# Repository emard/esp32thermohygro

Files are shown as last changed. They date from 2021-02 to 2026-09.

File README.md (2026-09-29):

# THERMOHYGROMETER

ESP32 2-channel SHT75/SHT85 thermohygrometer logger with OLED display
and web interface.

New Micropython version is recommended and full featured.

Old code for Arduino in directory heltec_kit_thermohygro supports SHT75 only.

# Install

Install Microypthon for ESP32-S3:

    pipx install esptool
    wget https://micropython.org/resources/firmware/ESP32_GENERIC_S3-SPIRAM_OCT-20260824-v1.29.0.bin
    esptool --port /dev/ttyACM0 --baud 460800 write_flash 0 ESP32_GENERIC_S3-SPIRAM_OCT-20260824-v1.29.0.bin

Install Thermohygrometer:

    pipx install mpremote
    mpremote mip install ssd1306
    mkdir -p lib
    wget https://raw.githubusercontent.com/miguelgrinberg/microdot/refs/heads/main/src/microdot/microdot.py -O lib/microdot.py
    wget https://raw.githubusercontent.com/BrianPugh/micropython-libs/refs/heads/main/lib/interp1d.py -O lib/interp1d.py
    mpremote cp -r *.py lib public_html :/

Install pye editor:

    mpremote mip install github:robert-hh/Micropython-Editor

Edit file "thwificfg.py" to enter WiFi access point username and password.
Thermologger needs internet access to set real time clock (RTC). Most
ESP32 boards usually don't have RTC running on battery.

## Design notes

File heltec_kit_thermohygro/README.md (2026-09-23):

# Arduino Thermo-Hygrometer for ESP32

# Controller

    HELTEC ESP32 LoRa KIT pinout top view

             GND o -- USB -- o GND
              5V o RST   PRG o  5v
             3V3 o           o 3v3
             GND o           o  36
              RX o           o  37
              TX o           o  38
             RST o  -------  o  39
    Button     0 o |       | o  34
         SCL1 22 o |       | o  35 
    LoRa MISO 19 o |       | o  32
         SCL2 23 o |       | o  33
    LoRa CS   18 o |       | o  25   LED
    LoRa SCK   5 o |       | o  26   LoRa IRQ
    OLED SCL  15 o |       | o  27   LoRa MOSI
               2 o |       | o  14   LoRa RST
    OLED SDA   4 o |       | o  12
              17 o  -------  o  13   SDA2
    OLED RST  16 o ----O---- o  21   SDA1

# Sensor Sensirion SHT75

[SHT75 datasheet](https://www.mouser.com/datasheet/2/682/Sensirion_Humidity_SHT7x_Datasheet_V5-469726.pdf)

       ----
      |HLM |
      | 75 |
       -  -
        ||
       -  -
      |    |
       ||||
       1234

    pin signal
    --- ---
     1  SCK
     2  VDD
     3  GND
     4  DATA

# Sensor in sonbest-slht14-5-RJ45 assembly

[slht14-5-RJ45 datasheet](http://www.sonbest.com/uploads/soft/151029/2-151029160H7.pdf)

        ----
     ---    ---
    |          |
    | 87654321 |
     ----------

    pin  color          signal
    ---  ------------   ------
     1   orange-white
     2   orange
     3   green-white    GND
     4   blue           SDA
     5   blue-white     SCK
     6   green          3V3
     7   brown-white
     8   brown

# Sensor in the Probus assembly

    Probus sensor DIN 8-pin
    Inside chip SHT75
    Text written on the chip
     ---
    |HLM|
    |75 |
     --- 
    
    looking at the pins DIN-8

                U
              6   7
             1  8  3
              4   5
                2
    
    pin signal
    --- -----
     4  SCK
     8  VDD
     1  GND
     6  DATA

# RJ45 adapter for Probus DIN 8-pin

    RJ45 crimped on cable, looking at the pins
    
        |c |
        |a |
        |b |
        |l |
        |e |
     ---    ---   
    |          |
    |          |
    | |||||||| |
    | 87654321 |
     ----------
    
    RJ45                         DIN-8
    pin  color          signal   pin
    ---  ------------   ------   -----
     1   green-white
     2   green
     3   orange-white   GND      1
     4   blue           DATA     6
     5   blue-white     SCK      4
     6   orange         VDD      8
     7   brown-white
     8   brown                   shield
    
    Probus sensor DIN 8-pin on cable, looking at the pins
    
                     U
    blue           6   7
    orange-white  1  8  3
    blue-white     4   5
                     2

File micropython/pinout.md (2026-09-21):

# Pinout

XIAO ESP32S3 SHT75/SHT85 SSD1306 I2C/SPI

looking at plastic package
back side is golden
     ┌────┐
     │HLM │
     │ 75 │
     └─┐┌─┘
       ││
     ┌─┘└─┐
     │    │
     └────┘
      ││││
      1234

    pin signal
    --- ---
     1  SCK
     2  VDD
     3  GND
     4  DATA

Sensor in sonbest-slht14-5-RJ45 assembly

    RJ45 socket
    looking at hole
    pins are down
       ┌────┐
    ┌──┘    └──┐
    │          │
    │ 87654321 │
    └──────────┘

    RJ45 crimped on cable
    looking at the pins
        │c │
        │a │
        │b │
        │l │
        │e │
    ┌──────────┐
    │   │  │   │
    │          │
    │          │
    │          │
    │ ││││││││ │
    │ 87654321 │
    └──────────┘

    pin  color          signal
    ---  ------------   ------
     1   orange-white
     2   orange
     3   green-white    GND
     4   blue           SDA
     5   blue-white     SCK
     6   green          3V3
     7   brown-white
     8   brown

                     XIAO  ESP32S3
                    ┌─────────────┐
    SHT75 2    SCK2 │1    USB   5V│
    SHT75 2    SDA2 │2         GND│
    SHT75 1    SCK1 │3        3.3V│
    SHT75 1    SDA1 │4           9│ RES Reset
    Chip select  CS │5           8│ D1  SDA/MOSI
    Data/Command DC │6  TX       7│ D0  SCL/SCK
                    │43 TXD  RX 44│
                    └─────────────┘
                       top view

      SSD1306 OLED I2C DISPLAY
    ┌──────────────────────────┐
    │     GND VCC SCL SDA      │
    │┌────────────────────────┐│
    ││                        ││
    ││          0.96"         ││
    ││         128x64         ││
    ││                        ││
    ││                        ││
    │└────────────────────────┘│
    └──────────────────────────┘
               top view

I2C
                 XIAO  ESP32S3
                ┌─────────────┐
                │1    USB   5V│
                │2         GND│
                │3        3.3V│
                │4           9│
                │5           8│ SDA
                │6  TX       7│ SCL
                │43 TXD  RX 44│
                └─────────────┘
                   top view

    SCL / D0    Pin     7       I2C Clock (SCL)
    SDA / D1    Pin     8       I2C Data  (SDA)

      SSD1306 OLED SPI DISPLAY
    ┌──────────────────────────┐
    │GND VCC D0  D1  RES DC  CS│
    │┌────────────────────────┐│
    ││                        ││
    ││          0.96"         ││
    ││         128x64         ││
    ││                        ││
    ││                        ││
    │└────────────────────────┘│
    └──────────────────────────┘
               top view

SPI

                     XIAO  ESP32S3
                    ┌─────────────┐
                    │1    USB   5V│
                    │2         GND│
                    │3        3.3V│
                    │4           9│ RES Reset
    Chip select  CS │5           8│ D1  MOSI
    Data/Command DC │6  TX       7│ D0  SCK
                    │43 TXD  RX 44│
                    └─────────────┘
                       top view

    SCL / D0    Pin     7       SPI Clock (SCK)
    SDA / D1    Pin     8       SPI Data (MOSI)
    RES / RST   Pin     9       Reset
    DC          Pin     6       Data / Command
    CS          Pin     5       Chip Select

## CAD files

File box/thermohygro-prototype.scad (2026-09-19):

// TH2 prototype on universal 2.54mm raster PCB

/* [STL element to export] */
//Coque haut - Top shell
  TShell        = 1;// [0:No, 1:Yes]
//Coque bas- Bottom shell
  BShell        = 1;// [0:No, 1:Yes]
//Panneau arrière - Back panel  
  BPanel        = 1;// [0:No, 1:Yes]
//Panneau avant - Front panel
  FPanel        = 1;// [0:No, 1:Yes]
//Texte façade - Front text
  Text          = 1;// [0:No, 1:Yes]


/*//////////////////////////////////////////////////////////////////
              -    FB Aka Heartman/Hearty 2016     -                   
              -   http://heartygfx.blogspot.com    -                  
              -       OpenScad Parametric Box      -                     
              -         CC BY-NC 3.0 License       -                      
////////////////////////////////////////////////////////////////////                                                                                                             
12/02/2016 - Fixed minor bug 
28/02/2016 - Added holes ventilation option                    
09/03/2016 - Added PCB feet support, fixed the shell artefact on export mode. 

*/////////////////////////// - Info - //////////////////////////////

// All coordinates are starting as integrated circuit pins.
// From the top view :

//   CoordD           <---       CoordC
//                                 ^
//                                 ^
//                                 ^
//   CoordA           --->       CoordB


////////////////////////////////////////////////////////////////////


////////// - Paramètres de la boite - Box parameters - /////////////

/* [PCB_Feet--TheBoard_Will_NotBeExported) ] */
//All dimensions are from the center foot axis
// - Coin bas gauche - Low left corner X position
PCBPosX         = 0;
// - Coin bas gauche - Low left corner Y position
PCBPosY         = 0;
// - Longueur PCB - PCB Length
PCBLength       = 15*2.54;
// - Largeur PCB - PCB Width
PCBWidth        = 18*2.54;
// - Heuteur pied - Feet height
FootHeight      = 6;
// - Diamètre pied - Foot diameter
FootDia         = 7;
// - Diamètre trou - Hole diameter
FootHole        = 1.8;
// - 3-foot mode, one foot width-asymmetric, 0 for normal 4-foot mode
Foot3Width = 0;

// those clearances should be larger than
// the PCB edge to hole centers distances
FootClrX = 7; // foot center to panel clearance
FootClrY = 10; // foot center to shell wall clearance

// - Epaisseur - Wall thickness  
Thick           = 2;//[2:5]  


/* [Box dimensions] */
// - Longueur - Length  
  Length        = PCBLength+2*(2*Thick+FootClrX);
// - Largeur - Width
  Width         = PCBWidth+2*(Thick+FootClrY);
// - Hauteur - Height  
  Height        = 24    ;
  
/* [Box options] */
// Pieds PCB - PCB feet (x4) 
  PCBFeet       = 1;// [0:No, 1:Yes]
// - Decorations to ventilation holes
  Vent          = 0;// [0:No, 1:Yes]
// - Decoration-Holes width (in mm)
  Vent_width    = 1.5;   
// - Text you want
  txt           = "CSS TH2";
// - Font size  
  TxtSize       = 7;
// - Font extruded height
  TxtHeight     = 1.5;
// - Font  
  Police        ="Arial Black"; 
// - Diamètre Coin arrondi - Filet diameter  
  Filet         = 2;//[0.1:12] 
// - lissage de l'arrondi - Filet smoothness  
  Resolution    = 20;//[1:100] 
// - Tolérance - Tolerance (Panel/rails gap)
  m             = 1.5;
// mounting legs clearance
  MountClearance = 0.1;
  // clearance between Top and Bottom shell
  ShellClearance = 0.4;


// mounting hole diameters
MountOuterHole = 2.5;
MountInnerHole = 1.8;

MountHoleXpos = 2;

// fixation leg size
MountLegSize = 16;
// fixation hole position from center
MountHolePos = 3;



  
/* [Hidden] */
// - Couleur coque - Shell color  
Couleur1        = "Orange";       
// - Couleur panneaux - Panels color    
Couleur2        = "OrangeRed";    
// Thick X 2 - making decorations thicker if it is a vent to make sure they go through shell
Dec_Thick       = Vent ? Thick*2 : Thick; 
// - Depth decoration
Dec_size        = Vent ? Thick*2 : 0.8;

//////////////////// Oversize PCB limitation -Actually disabled - ////////////////////
//PCBL= PCBLength+PCBPosX>Length-(Thick*2+7) ? Length-(Thick*3+20+PCBPosX) : PCBLength;
//PCBW= PCBWidth+PCBPosY>Width-(Thick*2+10) ? Width-(Thick*2+12+PCBPosY) : PCBWidth;
PCBL=PCBLength;
PCBW=PCBWidth;
//echo (" PCBWidth = ",PCBW);



/////////// - Boitier générique bord arrondis - Generic Fileted box - //////////

module RoundBox($a=Length, $b=Width, $c=Height){// Cube bords arrondis
                    $fn=Resolution;            
                    translate([0,Filet,Filet]){  
                    minkowski (){                                              
                        cube ([$a-(Length/2),$b-(2*Filet),$c-(2*Filet)], center = false);
                        rotate([0,90,0]){    
                        cylinder(r=Filet,h=Length/2, center = false);
                            } 
                        }
                    }
                }// End of RoundBox Module

      
////////////////////////////////// - Module Coque/Shell - //////////////////////////////////         

module Coque(top=0){//Coque - Shell  
    Thick = Thick*2;  
    difference(){    
        difference(){//sides decoration
            union(){    
                     difference() {//soustraction de la forme centrale - Substraction Fileted box
                      
                        difference(){//soustraction cube median - Median cube slicer
                            union() {//union               
                            difference(){//Coque    
                                RoundBox();
                                translate([Thick/2,Thick/2,Thick/2]){     
                                        RoundBox($a=Length-Thick, $b=Width-Thick, $c=Height-Thick);
                                        }
                                        }//Fin diff Coque                            
                                difference(){//largeur Rails        
                                     translate([Thick+m,Thick/2,Thick/2]){// Rails
                                          RoundBox($a=Length-((2*Thick)+(2*m)), $b=Width-Thick, $c=Height-(Thick*2));
                                                          }//fin Rails
                                     translate([((Thick+m/2)*1.55),Thick/2,Thick/2+0.1]){ // +0.1 added to avoid the artefact
                                          RoundBox($a=Length-((Thick*3)+2*m), $b=Width-Thick, $c=Height-Thick);
                                                    }           
                                                }//Fin largeur Rails
                                    }//Fin union                                   
                               translate([-Thick,-Thick,Height/2]){// Cube à soustraire
                                    cube ([Length+100, Width+100, Height], center=false);
                                            }                                            
                                      }//fin soustraction cube median - End Median cube slicer
                               translate([-Thick/2,Thick,Thick]){// Forme de soustraction centrale 
                                    RoundBox($a=Length+Thick, $b=Width-Thick*2, $c=Height-Thick);       
                                    }                          
                                }                                          

                if(top < 0.5)
                for(i = [0:1])
                difference(){// Fixation box legs
                    union(){
                        translate([i*(Length-6*Thick-10)+3*Thick+5,Thick,Height/2]){
                            rotate([90,0,0]){
                                    $fn=6;
                                    cylinder(d=MountLegSize,Thick/2);
                                    }   
                            }
                            
                       translate([i*(Length-6*Thick-10)+3*Thick+5,Width-Thick,Height/2]){
                            rotate([-90,0,0]){
                                    $fn=6;
                                    cylinder(d=MountLegSize,Thick/2);
                                    }   
                            }
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

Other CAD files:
box/thermohygro.scad

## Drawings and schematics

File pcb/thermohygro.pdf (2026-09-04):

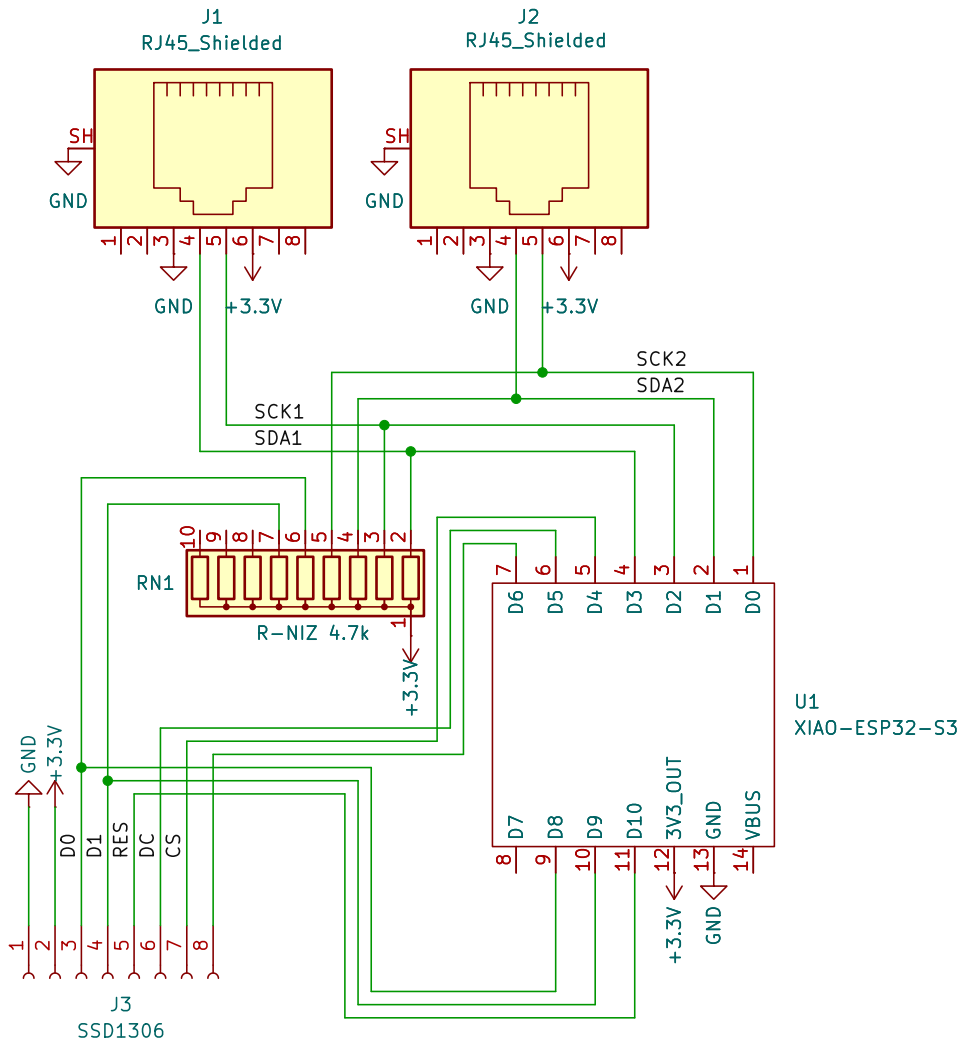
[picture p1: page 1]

Size: A4 | Rev: 1.2
KiCad E.D.A. 10.0.5 | Id: 1/1

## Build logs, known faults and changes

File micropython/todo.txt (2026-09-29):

[ ] on OLED show time, IP
[ ] on OLED show WiFi signal strength
[ ] from free bytes calculate max log date
[x] function with a localtime condition to trigger logging
[x] every new day resync ntptime
[x] log without parameter returs current log hours tuple
[x] sht75 max 1 measurement per second
[x] after log file is created, header is added but need to add first log line
[x] yearly log file
[x] on low storage free delete fist log year
[x] thweb.py: report log files of all years
[ ] delete one year of log after correctly answering a*b question
[x] log should return json {"basis":3, list:"1,2,3"}
[x] remove minutely log, as it localtime may skip partical second of a minute
[ ] on web log time is displayed as 14:12:59, done too early or esp32 rtc is late
[x] javascript: in download list, year that endsWith("9") should add <br/> newline
[x] help.html page
[x] feedback (OK,FAIL) at setting log events
[x] input field for hostname
[x] table mouse hover purple - why different color
[x] reboot
[ ] version

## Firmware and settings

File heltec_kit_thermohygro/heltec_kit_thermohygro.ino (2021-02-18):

// https://github.com/practicalarduino/SHT1x
#include <SHT1x.h>
#include <U8g2lib.h>
#ifdef U8X8_HAVE_HW_I2C
#include <Wire.h>
#endif

U8G2_SSD1306_128X64_NONAME_F_SW_I2C u8g2(U8G2_R0, /* clock=*/ 15, /* data=*/ 4, /* reset=*/ 16);// 
// Sensirion Sensor = Sensirion(Sensor_data[Sensor_use], Sensor_clock[Sensor_use]);
SHT1x Sensor[2] =
{ //  DATA, CLOCK
  SHT1x(21, 22),
  SHT1x(13, 23)
};

uint8_t Nsensors = 1; // 0-2 sensors present

char Ctemperature[2][10], Chumidity[2][10], Cip[20];

float Temperature[2], Humidity[2]; // x100 temperature and humidity
char IP[20];

void u8g2_prepare(void) {
  u8g2.setFont(u8g2_font_6x10_tf);
  u8g2.setFontRefHeightExtendedText();
  u8g2.setDrawColor(1);
  u8g2.setFontPosTop();
  u8g2.setFontDirection(0);
}

void u8g2_box_frame(uint8_t a) {
  u8g2.drawStr( 0, 0, "drawBox");
  u8g2.drawBox(5,10,20,10);
  u8g2.drawBox(10+a,15,30,7);
  u8g2.drawStr( 0, 30, "drawFrame");
  u8g2.drawFrame(5,10+30,20,10);
  u8g2.drawFrame(10+a,15+30,30,7);
}

void reading()
{
  digitalWrite(LED_BUILTIN, HIGH);
  #if 1
  for(int i = 0; i < 2; i++)
  {
    Temperature[i] = Sensor[i].readTemperatureC();
    Humidity[i] = Sensor[i].readHumidity();
  }
  #else
  for(int i = 0; i < 2; i++)
  {
    Temperature[i] = 0.1*((rand()%2000)-1000); // deg C
    Humidity[i] = 0.1*((rand()%1000)); // % RH
  }
  #endif
  digitalWrite(LED_BUILTIN, LOW);
}


void display1sensor(uint8_t i)
{
  if(Humidity[i] > -20.0 && Humidity[i] < 120.0)
  {
    snprintf(Ctemperature[i], sizeof(Ctemperature[0]), "%.1f%cC", Temperature[i], 0xB0);
    snprintf(Chumidity[i], sizeof(Chumidity[0]), "%.1f%%", Humidity[i]);
  }
  else
  {
    sprintf(Ctemperature[i], "___._%cC", 0xB0);
    sprintf(Chumidity[i], "___._%%");
  }
  sprintf(IP, "192.168.1.42");
  snprintf(Cip, sizeof(Cip), "%s", IP);
  u8g2.clearBuffer();
  u8g2.setFont(u8g2_font_fub25_tf); // proportional
  int w;
  w = u8g2.getStrWidth(Ctemperature[i]);
  u8g2.drawStr(127-w,0,Ctemperature[i]);
  w = u8g2.getStrWidth(Chumidity[i]);
  u8g2.drawStr(127-w,29,Chumidity[i]);
  u8g2.setFont(u8g2_font_6x10_tf); // proportional
  w =  u8g2.getStrWidth(Cip);
  u8g2.drawStr(127-w,56,Cip);
  u8g2.sendBuffer();
}

void display2sensors()
{
  for(int i = 0; i < 2; i++)
  {
    if(Humidity[i] > -20.0 && Humidity[i] < 120.0)
    {
      if(i == 0)
      {
        snprintf(Ctemperature[i], sizeof(Ctemperature[0]), "%.1f%cC", Temperature[i], 0xB0);
        snprintf(Chumidity[i], sizeof(Chumidity[0]), "%.1f%%", Humidity[i]);
      }
      else
      {
        snprintf(Ctemperature[i], sizeof(Ctemperature[0]), "%.1f", Temperature[i]);
        snprintf(Chumidity[i], sizeof(Chumidity[0]), "%.1f", Humidity[i]);
      }
    }
    else
    {
      if(i == 0)
      {
        sprintf(Ctemperature[i], "___._%cC", 0xB0);
        sprintf(Chumidity[i], "___._%%");
      }
      else
      {
        sprintf(Ctemperature[i], "___._");
        sprintf(Chumidity[i], "___._");
      }
    }
  }
  sprintf(IP, "192.168.1.42");
  snprintf(Cip, sizeof(Cip), "%s", IP);  
  u8g2.clearBuffer();
  u8g2.setFont(u8g2_font_fub14_tf); // proportional
  int w;
  int x = 72; // middle line
  w = u8g2.getStrWidth(Ctemperature[0]);
  u8g2.drawStr(x-w,0,Ctemperature[0]);
  w = u8g2.getStrWidth(Ctemperature[1]);
  u8g2.drawStr(127-w,0,Ctemperature[1]);
  w = u8g2.getStrWidth(Chumidity[0]);
  u8g2.drawStr(x-w,29,Chumidity[0]);
  w = u8g2.getStrWidth(Chumidity[1]);
  u8g2.drawStr(127-w,29,Chumidity[1]);
  u8g2.setFont(u8g2_font_6x10_tf); // proportional
  w =  u8g2.getStrWidth(Cip);
  u8g2.drawStr(127-w,56,Cip);
  u8g2.sendBuffer();
}

void refresh_display()
{
  #if 1
  if(Humidity[0] < -20.0 || Humidity[0] > 120.0)
  {
    display1sensor(1);
    return; 
  }
  if(Humidity[1] < -20.0 || Humidity[1] > 120.0)
  {
    display1sensor(0);
    return;
  }
  #endif
  display2sensors();
}


void setup() {
  Serial.begin(115200);
  u8g2.begin();
  u8g2_prepare();
  pinMode(LED_BUILTIN, OUTPUT);
}

void loop() {
  static uint8_t ledstate;
  reading();
  refresh_display();
  ledstate ^= 1;
  digitalWrite(LED_BUILTIN, ledstate);
  // delay(900);
}

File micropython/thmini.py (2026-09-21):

# simple reader app, low memory requirement
# shows result on display and prints on USB serial
# no web interface
from sht75 import SHT75
from sht85 import SHT85
import ssd1306txt

sensor1_scl_pin=const(3)
sensor1_sda_pin=const(4)
sensor2_scl_pin=const(1)
sensor2_sda_pin=const(2)

display_width=const(128)
display_height=const(64)
display_scl_pin=const(7)
display_sda_pin=const(8)
display_rst_pin=const(9)
display_dc_pin=const(6)
display_cs_pin=const(5)

ssd1306txt.init(disp_width=display_width,disp_height=display_height,
scl_pin=display_scl_pin,sda_pin=display_sda_pin,
rst_pin=display_rst_pin,dc_pin=display_dc_pin,cs_pin=display_cs_pin)

t1=-99.9
rh1=-99.9
model1=""
t2=-99.9
rh2=-99.9
model2=""
while True:
  if t1<-99:
    model1="SHT85"
    sensor1=SHT85(sck_pin=sensor1_scl_pin, data_pin=sensor1_sda_pin)
    if sensor1.detect()==False:
      model1="SHT75"
      sensor1=SHT75(sck_pin=sensor1_scl_pin, data_pin=sensor1_sda_pin, chip_v=4)
  t1,rh1,serial1=sensor1.read_temp_humidity()    
  if t1<-99:
    model1=""
  ssd1306txt.thdisp(1,model1,t1,rh1,serial1)
  if t2<-99:
    model2="SHT85"
    sensor2=SHT85(sck_pin=sensor2_scl_pin, data_pin=sensor2_sda_pin)
    if sensor2.detect()==False:
      model2="SHT75"
      sensor2=SHT75(sck_pin=sensor2_scl_pin, data_pin=sensor2_sda_pin, chip_v=4)
  t2,rh2,serial2=sensor2.read_temp_humidity()
  if t2<-99:
    model2=""
  ssd1306txt.thdisp(2,model2,t2,rh2,serial2)
  print("S1=%08X T1=%5.2f C RH1=%5.2f %% S2=%08X T2=%5.2f C RH2=%5.2f %% " % (serial1,t1,rh1,serial2,t2,rh2))

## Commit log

2021-02-18 arduino code
2026-06-16 fix sht85 humidity conversion formula
    [sht85.py]
2026-06-16 i2c/spi display autodetection
2026-06-16 3d printable box
2026-06-16 prints autoedetected sensor model SHT75/SHT85
2026-06-18 extend printable temp range from -99 to 200°C
2026-06-18 better display print values 0-100 with 1 decimal places and outside of that range as integers
2026-06-23 3D printable box TH1/TH2
    [thermohygro.scad]
2026-06-24 fine centering the opening for the usb and rj45 connectors
    [thermohygro.scad]
2026-06-26 smaller box as perfect fit for TH2
    [thermohygro.scad]
2026-06-26 print serial no
2026-08-02 kicad pcb
    [thermohygro.kicad_pcb, thermohygro.kicad_sch]
2026-08-02 schematics v0.9 pdf
    [thermohygro.kicad_sch]
2026-08-02 closer RJ45
    [thermohygro.kicad_pcb, thermohygro.kicad_sch]
2026-08-02 update kicad
    [thermohygro.kicad_pcb]
2026-08-02 display 2.54 mm up
    [thermohygro.kicad_pcb]
2026-08-02 move ESP32-S3 silkscreen dot showing pin 1
2026-08-02 new gerbers
    [thermohygro-B_Cu.gbr, thermohygro-B_Mask.gbr, thermohygro-Edge_Cuts.gbr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]
2026-08-02 pcb round corners
    [thermohygro.kicad_pcb]
2026-08-02 pullup for display i2c
    [thermohygro.kicad_pcb, thermohygro.kicad_sch]
2026-08-02 schematics 1.0
    [thermohygro.kicad_sch]
2026-09-04 fixed fatal PCB failure which permanently destroys SHT85 if plugged. RJ45 pins were reversed and now placed in correct order.
    [thermohygro.kicad_pcb, thermohygro.kicad_sch]
2026-09-04 gerbers PCB v1.1 fixed
    [thermohygro-B_Cu.gbr, thermohygro-B_Mask.gbr, thermohygro-Edge_Cuts.gbr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]
2026-09-04 schematics pdf updated
2026-09-04 fixed 5V connected wrong instead of 3.3V. Now 3.3V
    [thermohygro.kicad_pcb, thermohygro.kicad_sch]
2026-09-04 gerbers PCB v1.2 correctly powered by 3.3V (was 5V)
    [thermohygro-B_Cu.gbr, thermohygro-B_Mask.gbr, thermohygro-Edge_Cuts.gbr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]
2026-09-04 PDF v1.2 with 3.3V distributed power
2026-09-04 updated schematics with 8->10-pin R network, 7->8-pin display connector and additional wire to display
    [thermohygro.kicad_pcb, thermohygro.kicad_sch]
2026-09-04 pdf schematics update
2026-09-19 comment on top of prototype 3D box project file
    [thermohygro-prototype.scad]
2026-09-19 start new file for 3D printed box
    [thermohygro.scad]
2026-09-19 new 3D box dimensions, wip
    [thermohygro.scad]
2026-09-20 3D box good fit for new pcb
    [thermohygro.scad]
2026-09-21 cleanup from pinout, shorten the code to save esp32 RAM
2026-09-23 one reading per second to avoid sht75 heatup
    [sht75.py, thweb.py]
2026-09-23 improve sensor reading at every full second
2026-09-23 reset wifi for more reliable connect
    [thweb.py]
2026-09-24 log report without brackets and then strip " " and ","
2026-09-26 cleanup, setting log events shows status as WAIT/OK to the right of "SET" button
2026-09-26 input field for hostname with proper filter that prevents invalid names
2026-09-28 readme install ssd1306 display driver
2026-09-29 calibration example, untested
2026-09-29 max hostname is 32 chars for esp32
2026-09-29 tx power 14 of wifi fix bug using calib curve for rh
    [thweb.py]
2026-09-30 table examples as insiration for calibration table input
2026-10-05 wip calibration editable tables
2026-10-16 wip set calib, some debug prints in thweb.py and javascript sekeleton function is created that currently shows in innerHTML json that would be created (but it is not created yet, just a number 1234)
    no proper calib set function yet from web interface
2026-10-20 calibration tables web-editable
2026-10-26 calib.html note about how is calibration done
2026-10-30 fix calib empty json bug returning "}" instead of "{}" and some cleanup removing debug prints
2026-10-30 serial numbers in calib to upper case
2026-10-30 calib note for SHT75/SHT85 sensors
